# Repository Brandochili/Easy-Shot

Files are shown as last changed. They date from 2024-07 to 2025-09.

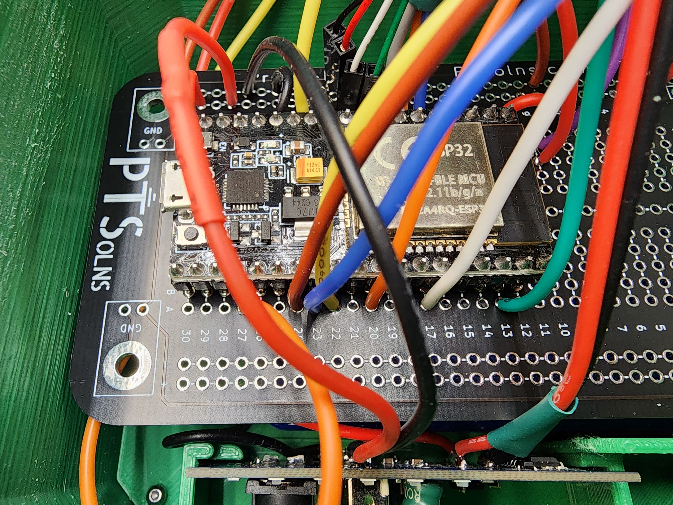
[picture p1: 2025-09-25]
20230622_110142.jpg

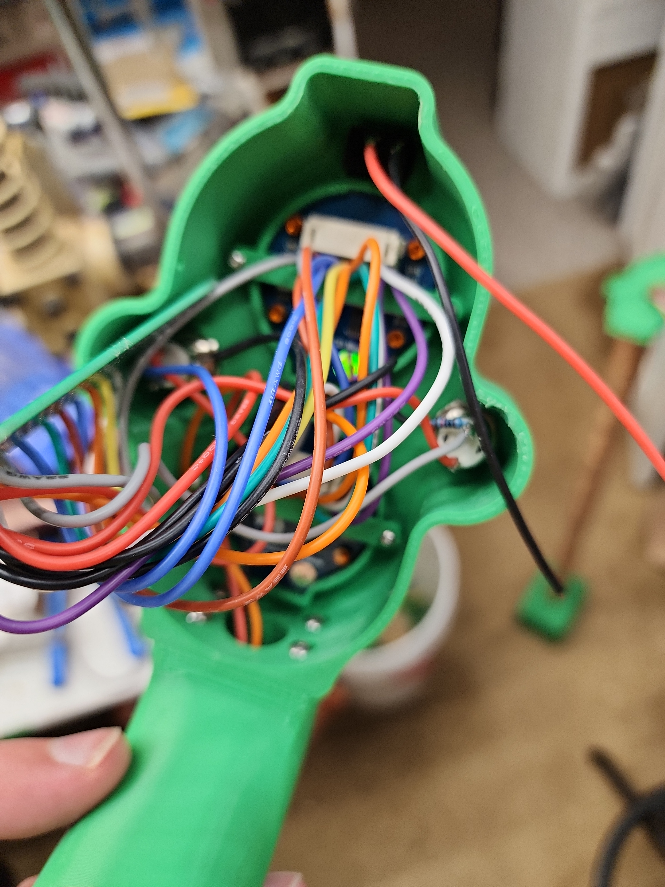
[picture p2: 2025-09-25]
IMG_20230622_111044_01.jpg

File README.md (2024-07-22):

# Easy-Shot
An open-sourced laser &amp; LiDAR distance measure for lawn bowling.

The Easy-Shot is a measuring device made to increase the physical accessibility of the sport of lawn bowling for aging members. This project research took place at the Regina Lawn Bowling Club. The device uses an ESP32 microcontroller, two IPS displays, two LiDAR sensors, a lithium-ion battery, a green laser line, three buttons, woodworking and 3D printing, to create a device that can take a distance measurement between a bowl and a jack to determine the shot bowl. This project is open-sourced and includes build plans, 3D print files, a purchasing list, a wiring diagram and the code.

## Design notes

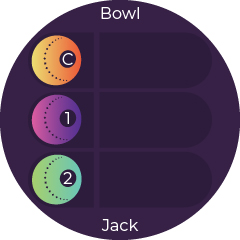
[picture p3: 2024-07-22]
dial_3.jpg

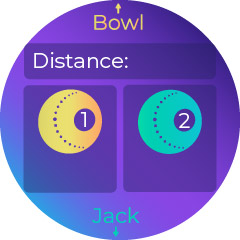
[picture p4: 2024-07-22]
dial.jpg

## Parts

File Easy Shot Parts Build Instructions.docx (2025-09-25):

Easy-Shot Distance Measure for Lawn Bowling:

Build Instructions:

Step 1 – Print and Prepare the Parts

- 3D Print the Components: Print the following files (1 of each unless noted):
  - Base
  - Battery lid
  - Button holder
  - Display mount
  - Dual round display back
  - Laser cap
  - Handle
  - Lid
  - 4 × Legs
  - Tip: PLA is easiest for beginners, PETG is stronger but trickier to print.
- Make the Pole (optional advanced step):
  - The pole is a wooden tube to hide the wires.
  - Glue two pieces of oak (or another hardwood) together after routing a groove down each piece.
  - Once dry, turn it on a lathe (or sand it round) so it’s smooth.

Step 2 – Open the Battery

- Use a small screwdriver to remove the screws on the Talentcell battery pack.
- Gently pull apart the shell (there’s some sticky tape inside — go slowly).
- Take out the battery and the small circuit board inside.
- Be careful with the wires — don’t yank them.

Step 3 – Build the Base

- Cut the battery wires so you can extend them.
- Place the battery into the 3D-printed base and cover it with the battery lid.
- Secure it with glue.
- Make sure the wires pass through the wire hole.
- Mount the ESP32 board and other electronics inside the base using hot glue or screws.
- Remove the original power switch from the battery pack — you’ll move this switch to the dual display holder later so it’s easier to use.

Step 4 – Connect the Displays

- Solder wires from the ESP32 to the two round LCD displays.
- You can use the included wires or add your own extension wires.
- Leave some slack so you don’t have tight connections.
- (Optional) Add quick connectors so you can unplug the displays if you need to take the device apart later.
- Note: Everything except the battery circuit runs on 5V DC.

Step 5 – Build the Handle

- Insert the push button into the 3D-printed handle.
- Solder wires from the button back to the ESP32.
- Insert the brass threaded inserts into the 3D-printed holes (a soldering iron works well to heat and press them in).
- This lets you screw the parts together without cracking the plastic.

Step 6 – Upload the Code

- Install the Arduino IDE on your computer.
- Connect the ESP32 board with a USB cable.
- Open the Easy-Shot code (from the GitHub page).
- Click Upload to send the program to the board.

Step 7 – Align the Laser

- Insert the green line laser module into the laser cap.
- Power on the device.
- Carefully aim the laser so it lines up straight across the bowls.
- Once aligned, super glue it in place so it doesn’t move.
- Every laser is a little different — take your time here. This is the trickiest part of the whole build!

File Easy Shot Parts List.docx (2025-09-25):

Easy-Shot Distance Measure for Lawn Bowling:

Parts List:

3D Printing Materials:

- 1 Roll of PLA or PETG filament for this device (use your preference)
- 3D Printer OR access to one
- Brass Nuts Embedment Nut Assortment Kit (https://www.amazon.ca/dp/B09SZG96X4?ref_=ppx_hzsearch_conn_dt_b_fed_asin_title_1)

Wood Parts:

- The pole was made by glueing 2 pieces of oak together after routing a grove through the middle of each to create a channel for cables to pass. The whole thing was then turned on a wood lathe.

Electronics Components:

- 1 X KeeYees Development Board 2.4 GHz (https://www.amazon.ca/dp/B07QCP2451?ref_=ppx_hzsearch_conn_dt_b_fed_asin_title_11&th=1)
- 2 X waveshare 1.28 inch Round LCD Displays (https://www.amazon.ca/dp/B095X1JDCM?ref_=ppx_hzsearch_conn_dt_b_fed_asin_title_3)
- DAOKI 22AWG Hook up Wire Kit (https://www.amazon.ca/dp/B08DTLGTRP?ref_=ppx_hzsearch_conn_dt_b_fed_asin_title_12&th=1)
- PTSolns Prototyping Solderable Breadboard (https://www.amazon.ca/PTSolns-Prototyping-Solderable-Breadboard-Proto-Half/dp/B08T7YNF3D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)
- 3 X Individual waterproof Push Buttons (https://www.amazon.ca/dp/B08671VD54?ref_=ppx_hzsearch_conn_dt_b_fed_asin_title_7)
- Talentcell Rechargeable 12V 3000mAh Lithium ion Battery (https://www.amazon.ca/dp/B01M7Z9Z1N?ref_=ppx_hzsearch_conn_dt_b_fed_asin_title_5)
- Robojax VL53L0X Time-of-Flight (ToF) Laser Distance Sensor Module (https://www.amazon.ca/dp/B07BMCSJKN?ref_=ppx_hzsearch_conn_dt_b_fed_asin_title_2)
- LiDAR Stemedu TFmini Plus Micro Range Finder Sensor 0.1m~12m (https://www.amazon.ca/dp/B07L8B2FVK?ref_=ppx_hzsearch_conn_dt_b_fed_asin_title_1)
- Green line Laser Module Industrial Laser Module (https://www.amazon.ca/dp/B0BTPPFF4J?ref_=ppx_hzsearch_conn_dt_b_fed_asin_title_5&th=1)

Other Build Materials:

- M2 M3 M4 M5 Stainless Steel Precise Metric Bolts (https://www.amazon.ca/dp/B07GXLFK1V?ref_=ppx_hzsearch_conn_dt_b_fed_asin_title_7&th=1)
- Glue
  - Hot glue
  - Super glue

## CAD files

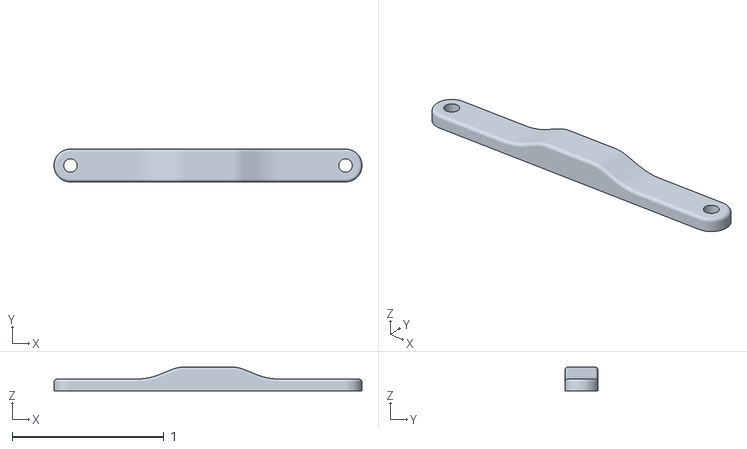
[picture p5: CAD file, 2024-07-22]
displaymount.stl
2.03 x 0.217 x 0.157

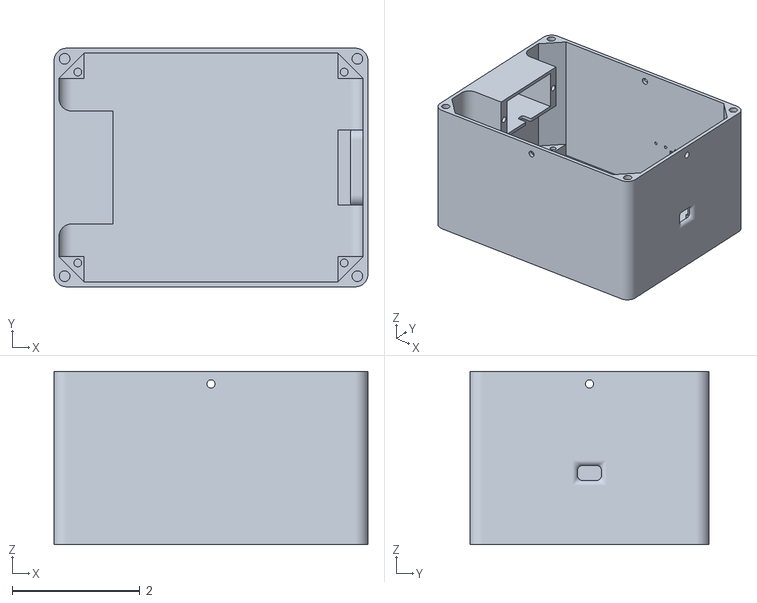
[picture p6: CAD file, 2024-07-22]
Base V2.stl
4.92 x 3.74 x 2.72

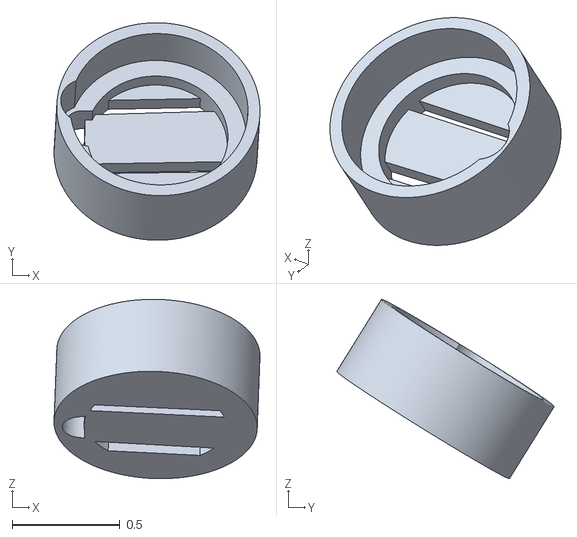
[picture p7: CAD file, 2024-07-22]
Dual Round Display Laser Cap.stl
0.957 x 1.01 x 0.833

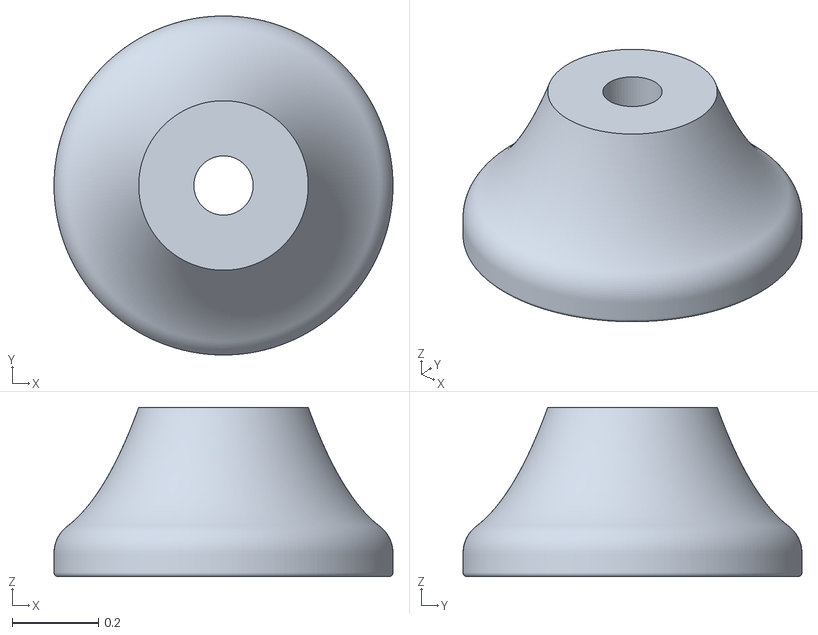
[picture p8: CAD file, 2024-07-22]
Leg V3.stl
0.787 x 0.787 x 0.394

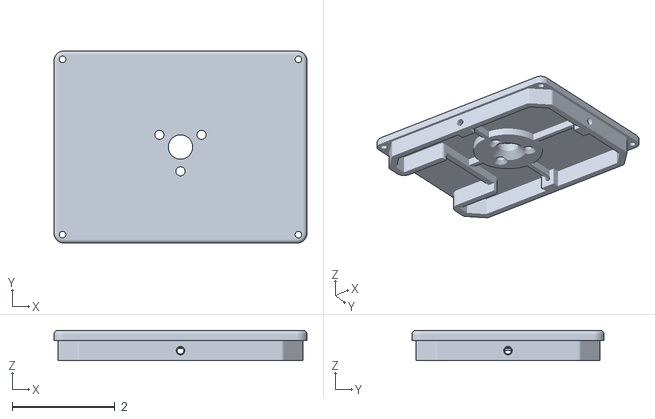
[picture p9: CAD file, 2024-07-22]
Lid V2.stl
4.92 x 3.74 x 0.591

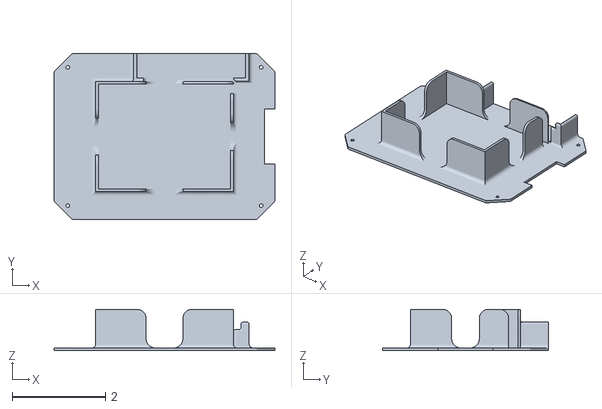
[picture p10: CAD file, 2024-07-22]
Battery Lid V2.stl
4.73 x 3.55 x 0.886

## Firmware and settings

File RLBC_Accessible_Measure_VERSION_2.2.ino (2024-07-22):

#include <TFT_eSPI.h>
#include <TJpg_Decoder.h>
#include "dial_3.h"
#include "Final_Frontier_28.h"

TFT_eSPI tft = TFT_eSPI();

bool tft_output(int16_t x, int16_t y, uint16_t w, uint16_t h, uint16_t* bitmap) {
  if (y >= tft.height()) return false;
  tft.pushImage(x, y, w, h, bitmap);
  return true;
}

void setup() {
  Serial.begin(115200);
  tft.begin();
  tft.fillScreen(TFT_WHITE);
  tft.setRotation(0);
  TJpgDec.setSwapBytes(true);
  TJpgDec.setCallback(tft_output);
}

void loop() {
  TJpgDec.drawJpg(0, 0, dial_3, sizeof(dial_3));
  tft.setTextWrap(true, true);
  Serial.println(tfDist);

  tft.loadFont(Final_Frontier_28);
  tft.setTextColor(TFT_WHITE);
  tft.setCursor(115, 52);
  tft.print("48.2");
  tft.println(" cm");
  tft.unloadFont();
}

delay(5000);
}
